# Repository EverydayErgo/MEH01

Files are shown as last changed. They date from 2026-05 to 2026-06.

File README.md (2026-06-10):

# **MEH01 replacement encoder for EVQWGD001**
 This is a very low cost (~ 1USD) full replacement for EVQWGD001 horizontal encoder. Project comes with all STL/STEP files for printing and incorporation into projects. It has the same base size as EVQWGD001 but due to different mounting mechanisms it won't "lock" into the EWQ* socket even though it fits. There are special openings in MEH01 socket where the encoder can "clip-in". 

Two versions are provided. With and without switch.

**If you're coming from a PCB that already has a EVQWGD001 footprint and would like to try this encoder there's a special adapter for that, [Socket adapter EVQWGD001](stl/adapter_evqwgd001.stl). As I don't have any keyboard with such footprint at hand I would like to ask you to test it out and provide feedback.**

## **KiCAD** symbol, footprint and 3D model is also available (untested), check my [KiCad Library](https://github.com/EverydayErgo/KiCAD)

||||||
|--|--|--|--|--|
||
||||||

|BOM|||
|--|--|--|
|**Item**|**Dimensions**|**Count**|
|[Kailh mouse encoder](img/kailh_1.png)|5mm|1|
|[MR63 RC Bearings (used in RC cars etc)](img/bearings_zzr.jpeg)|(M3)3mm x 6mm x 2mm|1|
|[Metal pin (bearing dowel)](img/metal_pin_1.jpg)|(M3)3mm x 6mm|1|
|[Tactile Push button](img/switch_1.jpg)|3mm x 4mm x 2mm|1|
|[AWG 30 Wire (best multi color)](img/wire_awg_30_1.jpg)||1|

Notice that the tactile switch has 1 leg, there's also version with 2 legs, this might be harder to solder wire to.

|STL||
|--|--|
|Item|Description|
|[Housing (switch)](stl/encoder_switch.stl)|Housing for the encoder with tactile switch|
|[Housing (no switch)](stl/encoder_no_switch.stl)|Housing for the encoder without switch|
|[Roller](stl/roller.stl)|Roller wheel|
|[Roller with insert](stl/roller_wire_core.stl)|Roller with 1.8 insert (metal wire/3D Filament)
|[Socket adapter EVQWGD001](stl/adapter_evqwgd001.stl)|Socket/mount for PCBs with EVQWGD001 footprint|

**Print with PETG with 0.4mm nozzle. For the roller use support.**

|STEP||
|--|--|
|Item|Description|
|[Housing (switch)](step/encoder_switch.stp)|Housing for the encoder with tactile switch|
|[Housing (no switch)](step/encoder_no_switch.stp)|Housing for the encoder without switch|
|[Roller](step/roller.stp)|Roller wheel|
|[Roller with insert](step/roller_wire_core.stp)|Roller with 1.8 insert (metal wire/3D Filament)
|[MEH01](step/MEH01.stp)|Full assembly|
|[Socket PCB](step/socket_pcb.stp)|Socket/mount for PCB|
|[Socket](step/socket.stp)|Socket/mount for keyboard plate|
|[Socket adapter EVQWGD001](step/adapter_evqwgd001.stp)|Socket/mount for PCBs with EVQWGD001 footprint|

Use these files to incorporate MEH01 into your CAD project.

## How to assemble
There are few live streams where I am building MEH01:
- [[Let's build #42] - Chordie, chording split mechanical keyboard you shouldn't be scared of
](https://youtu.be/GDPil8_5gyE?t=2537)
- [[Let's build #45] - Chordie, chording split mechanical keyboard you shouldn't be scared of
](https://youtu.be/FPBJ9f71gYo?t=291)

This one might come handy if you are using roller with insert, either metal wire or 3D printer filament. Same method applies to both.
- [[Let's build #80] - Chordie - keyboard project build. Part 2.](https://youtu.be/VZe0fLM2nms?t=3388)

|||||
|--|--|--|--|
||
|||||

For the version with tactile switch, solder AWG 30 wire to the switch terminals and route it. There's a canal under the switch to route left terminal, both should go via two holes on the side of the housing.



Push the bearing and metal pin inside the roller.



If you are using roller with an insert (metal wire/3D filament) you will have to use pliers to grab the piece of wire/filament and push it in trying to rotate it at the same time (refer to the [Youtube](https://youtu.be/VZe0fLM2nms?t=3388) video above). For the filament you can cut a piece that goes all the way to the back of the encoder, almost goes through). Wire will usually flatten a bit so cut it shorter so it only goes in a bit.

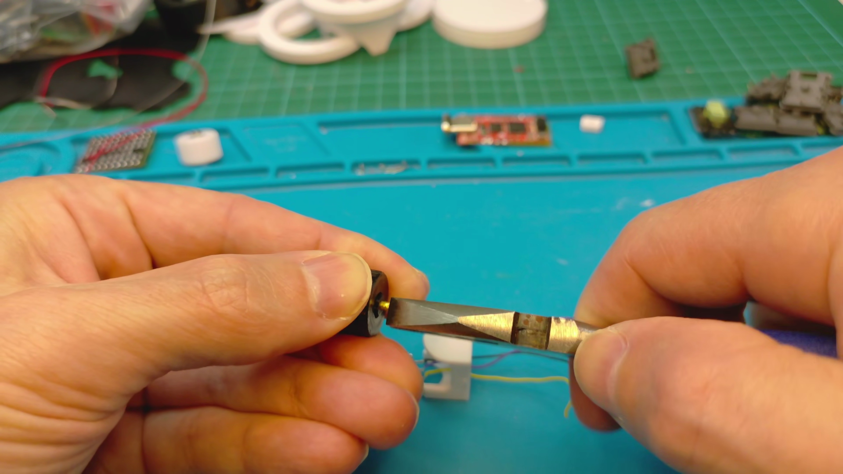
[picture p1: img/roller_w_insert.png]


Clip side mounting legs from the Kailh mouse encoder.



Solder wires to Kailh encoder terminals. Route them through the holes on the bottom of the housing. Back (black part) of the encoder should be facing the roller. Attach the roller. Take notice of encoder terminals, Com/A/B pins are in different positions as compared EVQWGD001, check the schematic below. Slide the encoder into the housing, you might want to start at 45 deg angle and then make you way. Check the stream if unshure on how to slide it in. 

|||||
|--|--|--|--|
||
|||||

There's a tiny clip inside the socket that should hold the housing quite well.

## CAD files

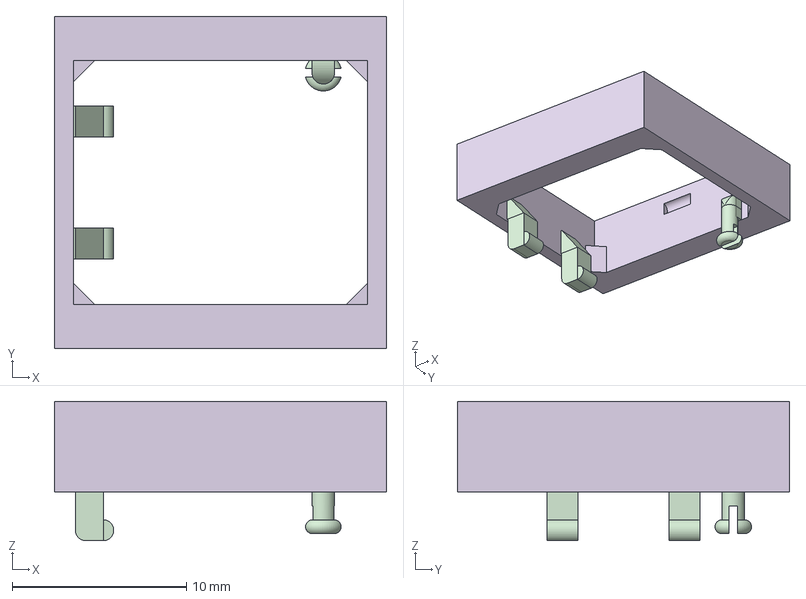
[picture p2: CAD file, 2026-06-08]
step/adapter_evqwgd001.stp
19.0 x 19.1 x 8.00 mm
Socket PCB EVQ Geometry

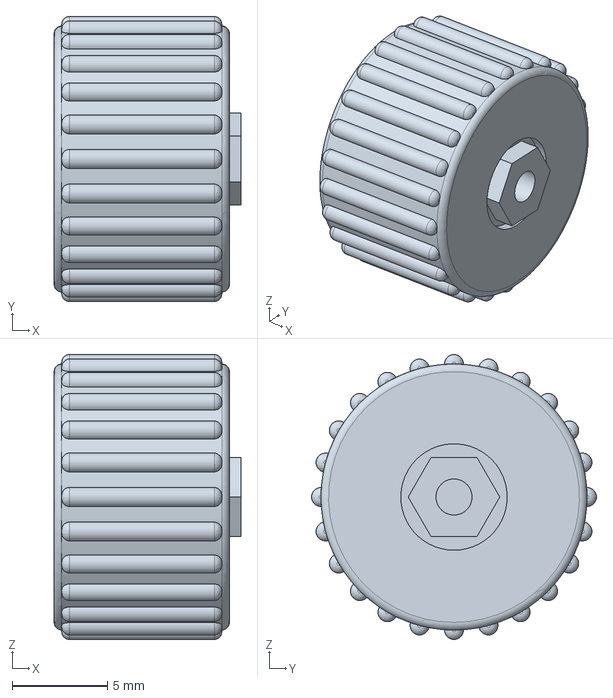
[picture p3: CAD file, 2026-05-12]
step/roller_wire_core.stp
9.83 x 15.0 x 15.0 mm

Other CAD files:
stl/adapter_evqwgd001.stl

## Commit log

2026-05-12 Added roller with wire core
    [roller_wire_core.stp]
2026-06-08 Added adapter for EVQWGD001
    [adapter_evqwgd001.stl, adapter_evqwgd001.stp]
